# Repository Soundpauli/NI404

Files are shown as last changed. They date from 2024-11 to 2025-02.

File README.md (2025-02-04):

DIY OPEN SOURCE HARDWARE SAMPLER-SEQUENCER

---------
An Etch-A-SketchTM inspired device for beginners and makers.

THE OPEN SOURCE SAMPLE-SEQUENCER FOR EVERYONE.
-------------
The NI404 is an innovative, open-source DIY sample-sequencer from SP_ (aka soundpauli) - inspired by the classic Etch-A-Sketch, tailored for beginners and DIY enthusiasts. Designed around the Teensy Microcontroller and Audioboard from PJRC, this device offers an accessible entry point into the world of music creation.
The NI404 is more than just a musical instrument; it's a journey into the world of sound exploration, perfect for live performances, studio sessions, or simply having fun creating music. Whether you're a seasoned musician or a curious beginner, the NI404 is your gateway to an exciting world of musical possibilities.

EASY TO USE.
-------------
With its playful design, the NI404 lets users create complex sound patterns without any prior knowledge of musical instruments or equipment. It's perfect for beginners and makers alike.

DYNAMIC CONTROL DESPITE LESS BUTTONS.
-------------
At the heart of the NI404 is a vivid 16x16 RGB LED panel display, paired with three intuitive rotary-push encoders. Navigate a cursor across the grid, where each row signifies a voice and each column a potential note, allowing for up to 16 pitches per note. This feature enables the mixing of up to 8 voices simultaneously.

REAL-TIME INTERACTION.
-------------
Adjust samples, instruments, pitches, notes, volume, BPM, velocity, and effects in real-time without pausing. This seamless interaction makes the NI404 an ideal gadget for live performances.

CORE COMPONENTS.
-------------
Teensy 4.1 Microcontroller and Teensy Audio board (4.0)
8MB PSRAM Flash Memory
3 Rotary-push encoders
16x16 RGB-LED Panel driven by FastLED
3.5mm audio jack and removable SD Microcard slot

CREATIVE FLEXIBILITY.
-------------
Etch-A-Sketch style note drawing
On-the-fly note deletion and sample muting
Adjustable volume, BPM (40 - 200), pattern, and note velocity
Up to 30-second sample length with seamless looping
Use your own samples on the SD-Card - in a simple file structure
Load up to 8 voices / samples (Wav format) plus an additional onboard synth voice
16-bar patterns across 8 pages, totaling 128 bars per song
Save and load up to 100 patterns / songs on the SD card
Autosave and autoload functions
SAMPLES AT YOUR FINGERTIPS:
THE BUILT-IN SAMPLE BROWSER.
Access and manage samples while playing, with support for up to 999 samples on the SD card and the ability to predefine multiple voices as a SampleSet.

FULLY INDEPENDENT.
-------------
Operates without a computer, generating all sounds on the device itself. USB powered (5V) and Arduino code is published under the MIT License.

Important: The NI404 does not include speakers or Bluetooth connectivity; Headphones are recommended. Because of licensing: please use your own sample files (folder structure is included).

READY FOR MORE.
-------------
Potential updates include USB-MIDI In & Out, and possible new features you are builing ;)

HARDWARE LIST
-------------
Custom PCB - to connect the encoders to the Teensy (but you can also hard wire everything): see Downloads
1x Teensy 4.1
1x Teensy Audio Adaptor / TEENSY4_AUDIO
2x PSRAM Chip for Teensy 4.1
4x Rotary Encoder KY-040 360degree + Push

Jumper Wire Cables (10cm)
1x Micro SD Card (Class 10)
(Micro SD-Extension)
1x 16x16 RGB LED Matrix

USED LIBRARIES
-------------
WS2812Serial
Teensy Audio Library (Audio.h, v1.0.6)
Quadrature Encoder Library from Paul Stoffregen (Encoder.h, v1.4.4)
Mapf (v1.0.2, GPL-3.0 license)
FastLED (v3.9.10, MIT License)
TeensyPolyphony (v1.0.7, MIT License)

>Important notice:
Dont forget to replace the ResamplingReader.h inside the newdigate/teensy-variable-playback library with the one from this directory - It helps a lot fighting nullptr errors ;)

Compiler-Switches
-------------
USB-Type: (Serial)+MIDI16X

LICENSE
-------------
The code is released under the MIT License, which means it's freely available for personal and commercial use, modification, distribution, and private copying. This permissive license is part of our effort to support innovation and creativity.

However, while the NI404 code itself is under the MIT License, we urge every user to be mindful of the dependencies and libraries utilized within the code. Each of these components may be governed by its own set of licenses. It's crucial for users to verify and ensure that they are in compliance with the licenses of all dependencies and libraries used in their projects. This step is important to respect the legal and ethical frameworks of open-source software.

So, whether you're a seasoned developer or a curious beginner, feel free to dive into the code, explore, modify, and create. Just remember to stay informed and respectful of the licensing requirements of all software components you use.

BUY A NI404
-------------
If you don't like to build your own NI404 (which i would recommend, it's an awesome project even for beginners), you can purchase 
the advances project: TOERN. See toern.live or github for more information.

GRATITUDE
-------------
I would like to extend my heartfelt thanks to Paul Stoffregen and everyone involved at PJRC for their incredible work in creating the Teensy environment and hardware. The innovation and dedication evident in Teensy have significantly impacted the DIY and maker communities, enabling countless creative projects and technological advancements.

Additionally, my gratitude goes out to the broader community of developers and enthusiasts who have contributed libraries for this remarkable piece of hardware. Your collective efforts and shared knowledge have not only enhanced the capabilities of Teensy but have also fostered a spirit of collaboration and open-source development, especially to Nic Newdigate, who contributed the awesome teensy-polyphony library, which is the "soul" of this project. Thanks!

Thank you all for your hard work, ingenuity, and commitment to making the Teensy platform a powerful and accessible tool for creators around the world.

Jan from SP_
Hamburg, January 2024

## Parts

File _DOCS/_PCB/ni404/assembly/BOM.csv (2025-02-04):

Reference | Value | Footprint | Qty | lcsc#
C1 | 1u | Capacitor_SMD:C_0402_1005Metric | 1 | C52923
C2 | 1u | Capacitor_SMD:C_0402_1005Metric | 1 | C52923
C3 | 10u | Capacitor_SMD:C_0603_1608Metric | 1 | C19702
C4 | 10u | Capacitor_SMD:C_0603_1608Metric | 1 | C19702
C5 | 10u | Capacitor_SMD:C_0603_1608Metric | 1 | C19702
C7 | 1u | Capacitor_SMD:C_0402_1005Metric | 1 | C52923
C8 | 1u | Capacitor_SMD:C_0402_1005Metric | 1 | C52923
C9 | 1u | Capacitor_SMD:C_0402_1005Metric | 1 | C52923
C10 | 100n | Capacitor_SMD:C_0402_1005Metric | 1 | C77020
C11 | 100n | Capacitor_SMD:C_0402_1005Metric | 1 | C77020
C12 | 1u | Capacitor_SMD:C_0402_1005Metric | 1 | C52923
C13 | 150n | Capacitor_SMD:C_0402_1005Metric | 1 | C162182
C14 | 100n | Capacitor_SMD:C_0402_1005Metric | 1 | C77020
C15 | 100n | Capacitor_SMD:C_0402_1005Metric | 1 | C77020
C16 | 10u | Capacitor_SMD:C_0603_1608Metric | 1 | C19702
C17 | 10u | Capacitor_SMD:C_0603_1608Metric | 1 | C19702
C18 | 10u | Capacitor_SMD:C_0603_1608Metric | 1 | C19702
C19 | 10u | Capacitor_SMD:C_0603_1608Metric | 1 | C19702
C20 | 10u | Capacitor_SMD:C_0603_1608Metric | 1 | C19702
C21 | 100n | Capacitor_SMD:C_0402_1005Metric | 1 | C77020
C22 | 10u | Capacitor_SMD:C_0603_1608Metric | 1 | C19702
C23 | 1u | Capacitor_SMD:C_0402_1005Metric | 1 | C52923
C24 | 10u | Capacitor_SMD:C_0603_1608Metric | 1 | C19702
C25 | 1u | Capacitor_SMD:C_0402_1005Metric | 1 | C52923
D1 | BAT54J | Diode_SMD:D_SOD-323F | 1 | C130415
D2 | MBR0540 | Diode_SMD:D_SOD-123 | 1 | C116159
D3 | LED | LED_SMD:LED_0603_1608Metric | 1 | C2286
J1 | AudioJack3_Switch | Connector_Audio:Jack_6.35mm_Neutrik_NMJ6HCD2_Horizontal | 1 | C368502
J2 | CUI_SJ2-35863B1-SMT-TR | myLibKicad:CUI_SJ2-35863B1-SMT-TR | 1 | C4992707
J3 | CUI_SJ2-35863B1-SMT-TR | myLibKicad:CUI_SJ2-35863B1-SMT-TR | 1 | C4992707
J4 | USB_C_Receptacle_USB2.0 | Connector_USB:USB_C_Receptacle_HRO_TYPE-C-31-M-12 | 1 | C165948
J5 | AudioJack3_Switch | Connector_Audio:Jack_6.35mm_Neutrik_NMJ6HCD2_Horizontal | 1 | C368502
J6 | AudioJack3_Switch | Connector_Audio:Jack_6.35mm_Neutrik_NMJ6HCD2_Horizontal | 1 | C368502
J7 | AudioJack3_Switch | Connector_Audio:Jack_6.35mm_Neutrik_NMJ6HCD2_Horizontal | 1 | C368502
J8 | Micro_SD_Card | Connector_Card:microSD_HC_Hirose_DM3BT-DSF-PEJS | 1 | C597972
J9 | Conn_01x03 | Connector_JST:JST_PH_B3B-PH-K_1x03_P2.00mm_Vertical | 1 | C131339
J11 | Conn_01x05 | Connector_JST:JST_PH_B5B-PH-K_1x05_P2.00mm_Vertical | 1 | C157993
J12 | Conn_01x05 | Connector_JST:JST_PH_B5B-PH-K_1x05_P2.00mm_Vertical | 1 | C157993
J13 | Conn_01x05 | Connector_JST:JST_PH_B5B-PH-K_1x05_P2.00mm_Vertical | 1 | C157993
J14 | Conn_01x05 | Connector_JST:JST_PH_B5B-PH-K_1x05_P2.00mm_Vertical | 1 | C157993
J15 | Conn_01x05 | Connector_JST:JST_PH_B5B-PH-K_1x05_P2.00mm_Vertical | 1 | C157993
J16 | BATTERY | Connector_JST:JST_PH_B2B-PH-K_1x02_P2.00mm_Vertical | 1 | C131337
MK1 | Microphone_Condenser | Sensor_Audio:POM-2244P-C3310-2-R | 1 | C3273559
Q1 | DMG3415 | Package_TO_SOT_SMD:SOT-23 | 1 | C7202986
R1 | 22R | Resistor_SMD:R_0402_1005Metric | 1 | C25092
R2 | 22R | Resistor_SMD:R_0402_1005Metric | 1 | C25092
R3 | 22R | Resistor_SMD:R_0402_1005Metric | 1 | C25092
R4 | 22R | Resistor_SMD:R_0402_1005Metric | 1 | C25092
R5 | 22R | Resistor_SMD:R_0402_1005Metric | 1 | C25092
R6 | 220R | Resistor_SMD:R_0603_1608Metric | 1 | C22962
R7 | 220R | Resistor_SMD:R_0603_1608Metric | 1 | C22962
R8 | 220R | Resistor_SMD:R_0603_1608Metric | 1 | C22962
R9 | 5.1k | Resistor_SMD:R_0402_1005Metric | 1 | C25905
R10 | 5.1k | Resistor_SMD:R_0402_1005Metric | 1 | C25905
R11 | 2k2 | Resistor_SMD:R_0603_1608Metric | 1 | C4190
R12 | 10k | Resistor_SMD:R_0402_1005Metric | 1 | C98220
R13 | 10k | Resistor_SMD:R_0402_1005Metric | 1 | C98220
R14 | 2k | Resistor_SMD:R_0603_1608Metric | 1 | C22975
R16 | 10k | Resistor_SMD:R_0402_1005Metric | 1 | C98220
R17 | 10k | Resistor_SMD:R_0402_1005Metric | 1 | C98220
R18 | 2k | Resistor_SMD:R_0603_1608Metric | 1 | C22975
SW1 | EG2219 | myLibKicad:EG2219 | 1 | C3664594
U1 | SPX3819M5-L-3-3 | Package_TO_SOT_SMD:SOT-23-5 | 1 | C9055
U2 | SPX3819M5-L-1-8 | Package_TO_SOT_SMD:SOT-23-5 | 1 | C24639
U3 | SGTL5000XNBA3 | Package_DFN_QFN:QFN-32-1EP_5x5mm_P0.5mm_EP3.6x3.6mm | 1 | C5196742
U4 | TLP2361V4_E | myLibKicad:5pin SO6_TOS | 1 | C107626
U5 | 74LVC2G14 | Package_TO_SOT_SMD:SOT-23-6 | 1 | C12401
U7 | SPX3819M5-L-3-3 | Package_TO_SOT_SMD:SOT-23-5 | 1 | C9055
U8 | MCP73831-3-OT | Package_TO_SOT_SMD:SOT-23-5 | 1 | C14879
U9 | 01x05 Connector_PinSocket_2.54mm | Connector_PinSocket_2.54mm:DuppaI2CEncoderV2.1 | 1 | C50950
U10 | 01x05 Connector_PinSocket_2.54mm | Connector_PinSocket_2.54mm:DuppaI2CEncoderV2.1 | 1 | C50950
U11 | 01x05 Connector_PinSocket_2.54mm | Connector_PinSocket_2.54mm:DuppaI2CEncoderV2.1 | 1 | C50950
U12 | 01x05 Connector_PinSocket_2.54mm | Connector_PinSocket_2.54mm:DuppaI2CEncoderV2.1 | 1 | C50950
U13 | 01x05 Connector_PinSocket_2.54mm | Connector_PinSocket_2.54mm:DuppaI2CEncoderV2.1 | 1 | C50950
U14 | 01x05 Connector_PinSocket_2.54mm | Connector_PinSocket_2.54mm:DuppaI2CEncoderV2.1 | 1 | C50950
U15 | 01x05 Connector_PinSocket_2.54mm | Connector_PinSocket_2.54mm:DuppaI2CEncoderV2.1 | 1 | C50950
U16 | 01x05 Connector_PinSocket_2.54mm | Connector_PinSocket_2.54mm:DuppaI2CEncoderV2.1 | 1 | C50950

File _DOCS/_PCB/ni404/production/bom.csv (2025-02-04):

Designator | Footprint | Quantity | Value | LCSC Part #
J11, J12, J13, J14, J15 | JST_PH_B5B-PH-K_1x05_P2.00mm_Vertical | 5 | Conn_01x05
J9 | JST_PH_B3B-PH-K_1x03_P2.00mm_Vertical | 1 | Conn_01x03

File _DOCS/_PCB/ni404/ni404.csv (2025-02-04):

Id | Designator | Footprint | Quantity | Designation | Supplier and ref
1 | J15,J11,J12,J13,J14 | JST_PH_B5B-PH-K_1x05_P2.00mm_Vertical | 5 | Conn_01x05
2 | J9 | JST_PH_B3B-PH-K_1x03_P2.00mm_Vertical | 1 | Conn_01x03

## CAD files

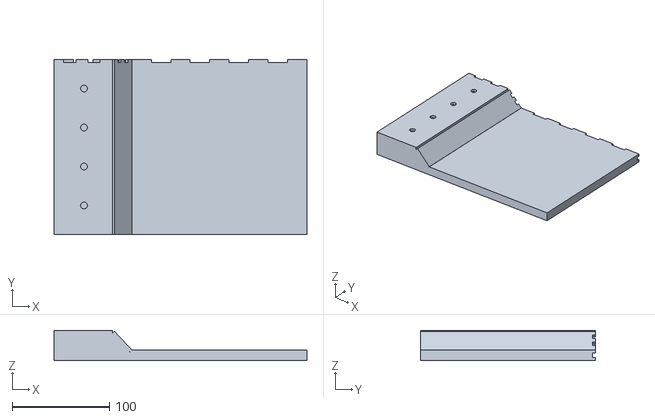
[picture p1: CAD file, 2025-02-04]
_DOCS/_ENCLOSURE/ni404 completed.stl
260.0 x 180.0 x 31.0

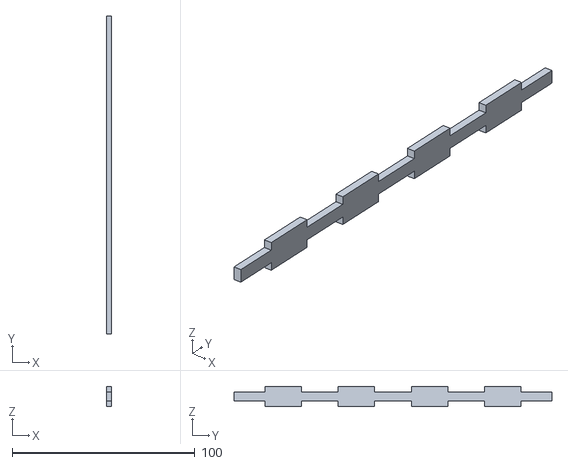
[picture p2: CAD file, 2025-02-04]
_DOCS/_ENCLOSURE/ni404_front.stl
3.00 x 174.0 x 11.0

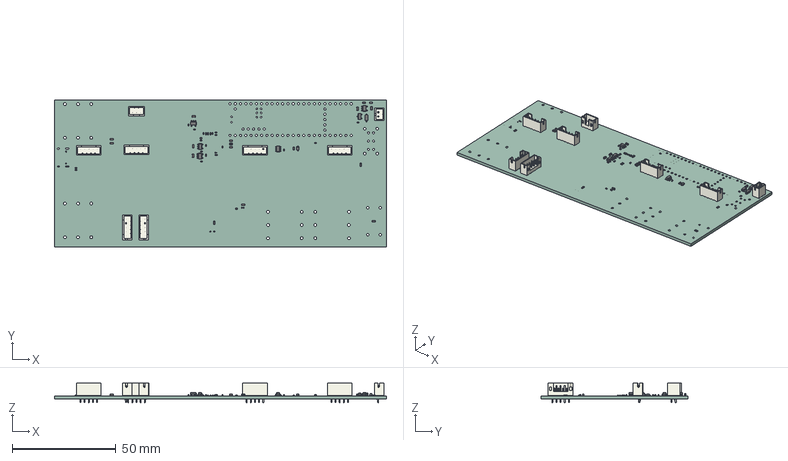
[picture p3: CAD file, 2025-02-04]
_DOCS/_PCB/ni404/ni404.step
160.0 x 71.0 x 9.40 mm
D_SOD_123
C_0402_1005Metric x 14
R_0603_1608Metric x 6
R_0402_1005Metric x 11
JST_B5B_PH_K x 6
C_0603_1608Metric x 10
SOT_23_6
SOT_23_5 x 4
JST_B3B_PH_K
LED_0603_1608Metric
SOT_23
JST_B2B_PH_K
D_SOD_323F
teensyAudioMidi_PCB

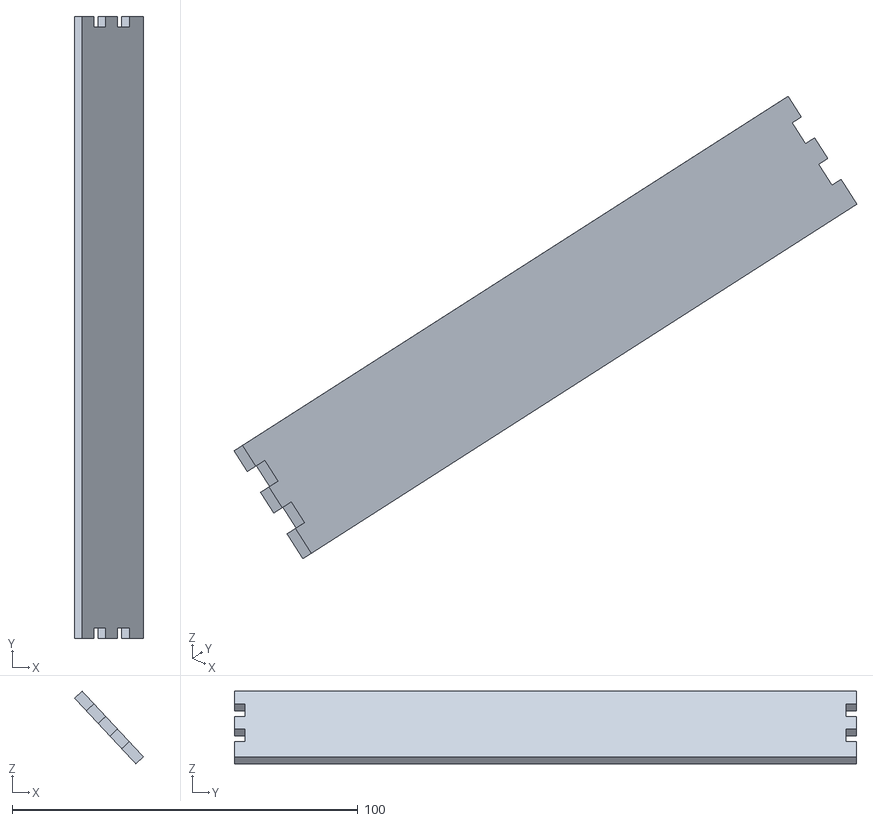
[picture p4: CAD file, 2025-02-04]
_DOCS/_ENCLOSURE/ni404_frontplate.stl
19.9 x 180.0 x 21.1

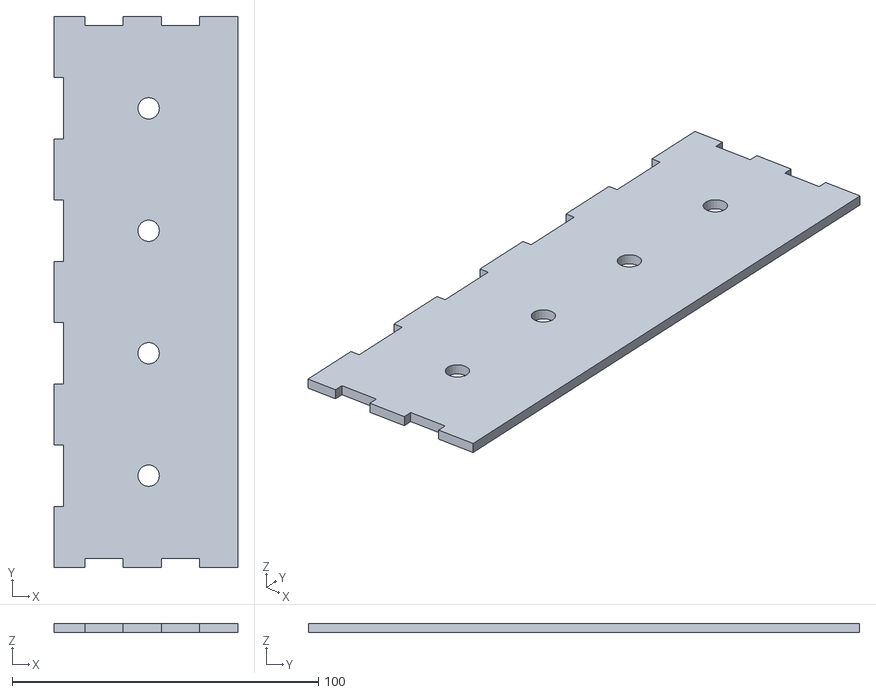
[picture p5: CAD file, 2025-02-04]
_DOCS/_ENCLOSURE/ni404_top.stl
60.0 x 180.0 x 3.00

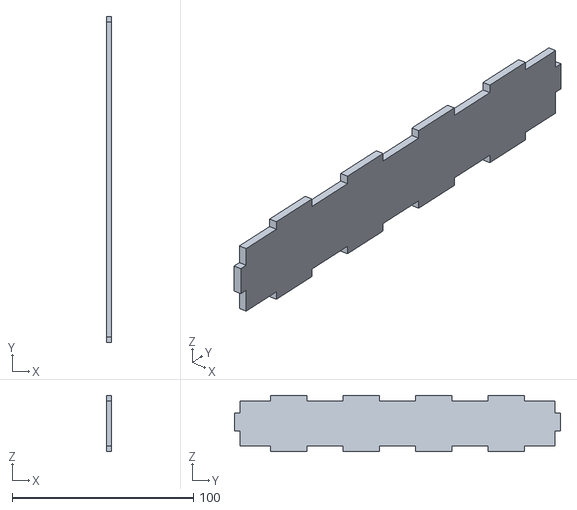
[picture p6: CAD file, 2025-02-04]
_DOCS/_ENCLOSURE/ni404_back.stl
3.00 x 180.0 x 31.0

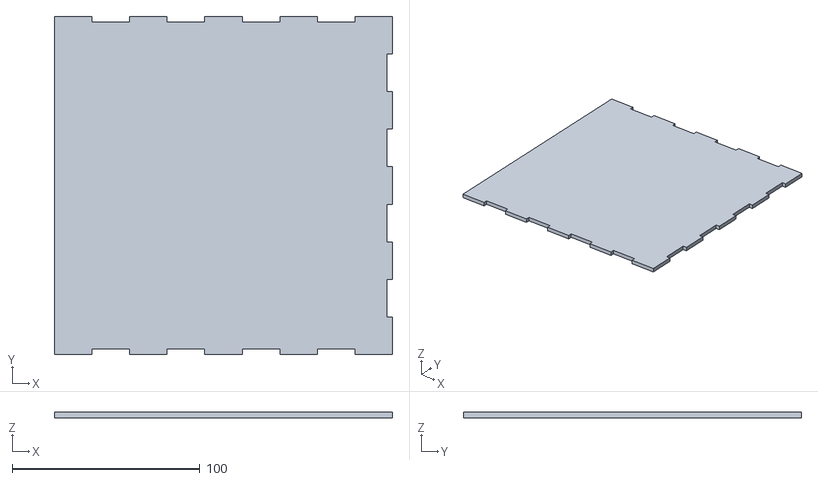
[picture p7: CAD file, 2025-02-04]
_DOCS/_ENCLOSURE/ni404_glassplate.stl
180.0 x 180.0 x 3.00

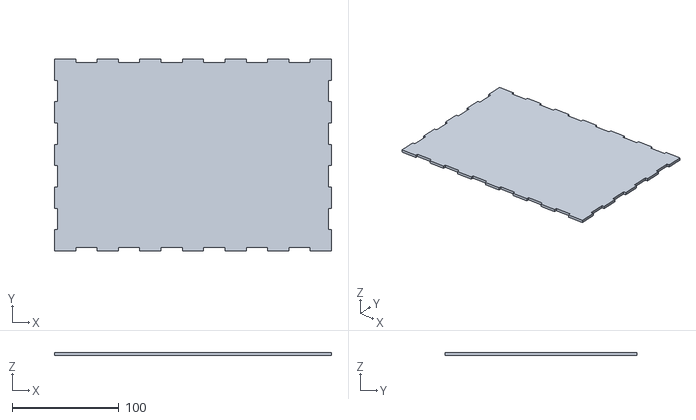
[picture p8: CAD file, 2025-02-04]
_DOCS/_ENCLOSURE/ni404_base.stl
260.0 x 180.0 x 3.00

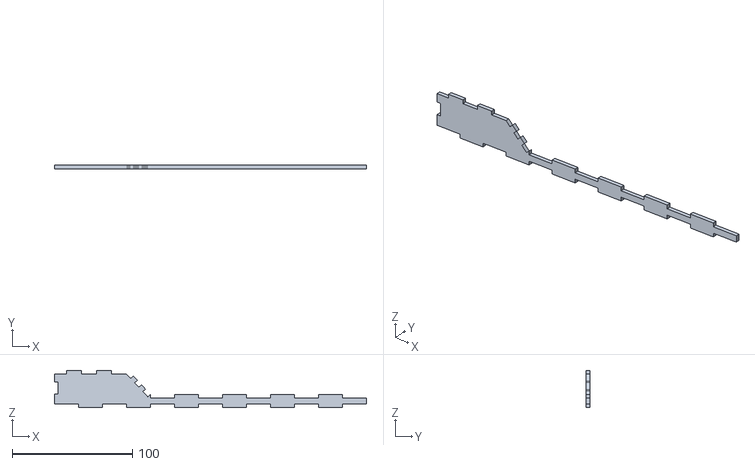
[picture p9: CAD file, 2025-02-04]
_DOCS/_ENCLOSURE/ni404_sides.stl
260.0 x 3.00 x 31.0

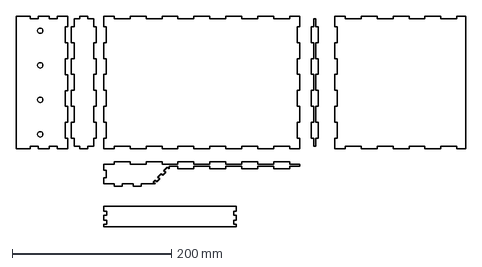
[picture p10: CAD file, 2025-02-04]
_DOCS/_ENCLOSURE/ni_404.dxf
564.2 x 264.5 mm

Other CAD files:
_DOCS/_ENCLOSURE/ni_404.f3d

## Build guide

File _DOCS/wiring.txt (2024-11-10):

Wiring for 3-4 Encoder-Version (1.0-1.x)
------------------------------------------------

> LED-Matrix:
DIN - Teensy: 17
+5V - Teensy: +5V
GND - Teensy: GND

> Encoder Left:
CLK - Teensy: 5
DT  - Teensy: 22
Switch - Teensy: 15
+3v - 3V
GND - GND

> Encoder Middle left:
CLK - Teensy: 32
DT  - Teensy: 33
Switch  - Teensy: 41
+3v - 3V
GND - GND

> Encoder Middle right:
CLK - Teensy: 9
DT  - Teensy: 14
Switch  - Teensy: 16
+3v - 3V
GND - GND

> Encoder Right:
CLK - Teensy: 4
DT  - Teensy: 2
Switch  - Teensy: 3
+3v - 3V
GND - GND

> DAC_PCB (backpack-PCB until v.1.x, included in v.2)
BCK - Teensy: 21
DIN - Teensy: 7
DOUT - Teensy: 8
WS  - Teensy: 20
+3  - 3V
GND - GND

Overall used pins:
------------------------------------------------

0   ->  MIDI IN 
1   ->  MIDI OUT
2   ->  NI=>Right Encoder CLOCK
3   ->  NI=>Right Encoder BUTTON
4   ->  NI=>Right Encoder BUS
5   ->  NI=>Left Encoder CLOCK
6   ->  MEMORYCHIP  
7   ->  AudioDAC DIN
8   ->  AudioDAC DOUT
9   ->  NI=>Middle Encoder CLOCK
10  ->  ChipSelect CS for SD 
11  ->  Data Storage (SPI) from Teensy to SD/MEM
12  ->  Data Storage (SPI) from SD/MEM to Teensy
13  ->  Data Storage (SPI) Clock
14  ->  NI=>Middle Encoder BUS
15  ->  NI=> Left Encoder BUTTON (+volume?)
16  ->  NI=> Middle Encoder BUTTON
17  ->  NI=> LED-MAXTRIX DIN
18  ->  Control Data (I2C)
19  ->  Control Clock (I2C)
20  ->  Audio Left/Right Clock, 44.1 kHz
21  ->  Audio Bit Clock, 1.41 or 2.82 MHz
22  ->  NI=>Left Encoder BUS
23  ->  Audio Master Clock, 11.29 MHz
32  ->  NI=>Middle Encoder BUS
33  ->  NI=>Middle Encoder CLOCK
41  ->  NI=>Middle Encoder BUTTON

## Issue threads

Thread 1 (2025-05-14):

Compiling issue

sinitsinmike, 2025-05-14:
After installing libraries of specified version I'm having issue compiling.
Followed the readme.
Is it possible to share precompiled hex file for the teensy4.1. it would be very easy to flash the hex file even for inexperienced users :)

Thank you!

sinitsinmike, 2025-05-14:
Tried compiling using arduino ide and VS Code.
I have failed to compile in both cases ;)
I've contacted you over the email. Applied your suggestions, but still no luck.

In any case just wanted to thank you for the great project and for trying to help.
I'm no pro in programming, but quite good at soldering :)

Thanks again!
Michael

Soundpauli, 2025-05-14:
Could you post the full compiler output including all used libraries+versions?
It seems as if you might be using the wrong versions of the newdigate libraries:

IDE 2.3.2
Teensyduino 1.59.0
Encoder 1.4.4
adv_switch 1.2.7  (or 1.2.8)
FastLED 3.9.16

>> Audiosample aka Teensy-Polyphony: https://github.com/newdigate/teensy-polyphony 1.0.7
>> Teensy-Variable-Playback:  https://github.com/newdigate/teensy-variable-playback 1.0.16

Please set to these versions and try again

sinitsinmike, 2025-05-14:
Will doublecheck the versions.

At this point I get:

[NI404 build log.txt](https://github.com/user-attachments/files/20213698/NI404.build.log.txt)
This is actually an *.rtf file. Not allowed to attach those. So just changed the extension.

sinitsinmike, 2025-05-14:
Changed some lib versions.
Attaching a txt log.

[NI404 build log2.txt](https://github.com/user-attachments/files/20213824/NI404.build.log2.txt)

sinitsinmike, 2025-05-14:
Tried the versions specified in README.md
USED LIBRARIES
-------------
WS2812Serial
Teensy Audio Library (Audio.h, v1.0.6)
Quadrature Encoder Library from Paul Stoffregen (Encoder.h, v1.4.4)
Mapf (v1.0.2, GPL-3.0 license)
FastLED (v3.9.10, MIT License)
TeensyPolyphony (v1.0.7, MIT License)

Should these be:
FastLED 3.9.16? instead of v3.9.10?

sinitsinmike, 2025-05-14:
Multiple libraries were found for "Encoder.h"
  Used: /Users/michaelsinitsin/Documents/Arduino/libraries/Encoder
  Not used: /Users/michaelsinitsin/Library/Arduino15/packages/teensy/hardware/avr/1.59.0/libraries/Encoder
Using library Mapf at version 1.0.2 in folder: /Users/michaelsinitsin/Documents/Arduino/libraries/Mapf
Using library WS2812Serial in folder: /Users/michaelsinitsin/Library/Arduino15/packages/teensy/hardware/avr/1.59.0/libraries/WS2812Serial (legacy)
Using library FastLED at version 3.9.16 in folder: /Users/michaelsinitsin/Documents/Arduino/libraries/FastLED
Using library SPI at version 1.0 in folder: /Users/michaelsinitsin/Library/Arduino15/packages/teensy/hardware/avr/1.59.0/libraries/SPI
Using library Audio at version 1.3 in folder: /Users/michaelsinitsin/Library/Arduino15/packages/teensy/hardware/avr/1.59.0/libraries/Audio
Using library SD at version 2.0.0 in folder: /Users/michaelsinitsin/Library/Arduino15/packages/teensy/hardware/avr/1.59.0/libraries/SD
Using library SdFat at version 2.1.2 in folder: /Users/michaelsinitsin/Library/Arduino15/packages/teensy/hardware/avr/1.59.0/libraries/SdFat
Using library SerialFlash at version 0.5 in folder: /Users/michaelsinitsin/Library/Arduino15/packages/teensy/hardware/avr/1.59.0/libraries/SerialFlash
Using library Encoder at version 1.4.4 in folder: /Users/michaelsinitsin/Documents/Arduino/libraries/Encoder
Using library Switch at version 1.2.7 in folder: /Users/michaelsinitsin/Documents/Arduino/libraries/Switch
Using library EEPROM at version 2.0 in folder: /Users/michaelsinitsin/Library/Arduino15/packages/teensy/hardware/avr/1.59.0/libraries/EEPROM
Using library TeensyAudioSampler at version 1.0.7 in folder: /Users/michaelsinitsin/Documents/Arduino/libraries/TeensyAudioSampler
Using library TeensyVariablePlayback at version 1.0.16 in folder: /Users/michaelsinitsin/Documents/Arduino/libraries/TeensyVariablePlayback
Using library LittleFS at version 1.0.0 in folder: /Users/michaelsinitsin/Library/Arduino15/packages/teensy/hardware/avr/1.59.0/libraries/LittleFS
Using library Wire at version 1.0 in folder: /Users/michaelsinitsin/Library/Arduino15/packages/teensy/hardware/avr/1.59.0/libraries/Wire
exit status 1

Soundpauli, 2025-05-15:
Solution 1:
make sure to #include "Arduino.h" in the main ino.

>From Arduino.h:

typedef unsigned int word;
typedef uint8_t boolean;
typedef uint8_t byte;

Solution 2:
At the top of any .h or .cpp file in TeensyAudioSampler that uses byte, add:

"using ::byte;"

This will make sure it resolves to the Arduino-style uint8_t version.
Alternative Fix (More Explicit): Change all uses of byte to uint8_t in the code.

sinitsinmike, 2025-05-15:
Thank you!
Where do I need to paste the following?:
"From Arduino.h:

typedef unsigned int word;
typedef uint8_t boolean;
typedef uint8_t byte; "

sinitsinmike, 2025-05-15:
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
Using this one.

sinitsinmike, 2025-05-16:
Are you using VS Code for compiling? Or something else?
I've found your new upcoming project. You've mentioned it is not ready on the web page.
Tried to build that one as well and failed :)

Soundpauli, 2025-05-23:
did you manage to compile?
if not, i added a precompiled hex file in the git, finally :)

[](https://github.com/Soundpauli/NI404/blob/main/build/teensy.avr.teensy41/soundpauli_ni404.ino.hex)

Soundpauli, 2025-05-23:
the teensy audio library uses the  stgl5000 at the moment. but you can change this in the code, i guess:

https://forum.pjrc.com/index.php?threads/pcm5012-i2s-dac-with-teensy-4-1.68625/

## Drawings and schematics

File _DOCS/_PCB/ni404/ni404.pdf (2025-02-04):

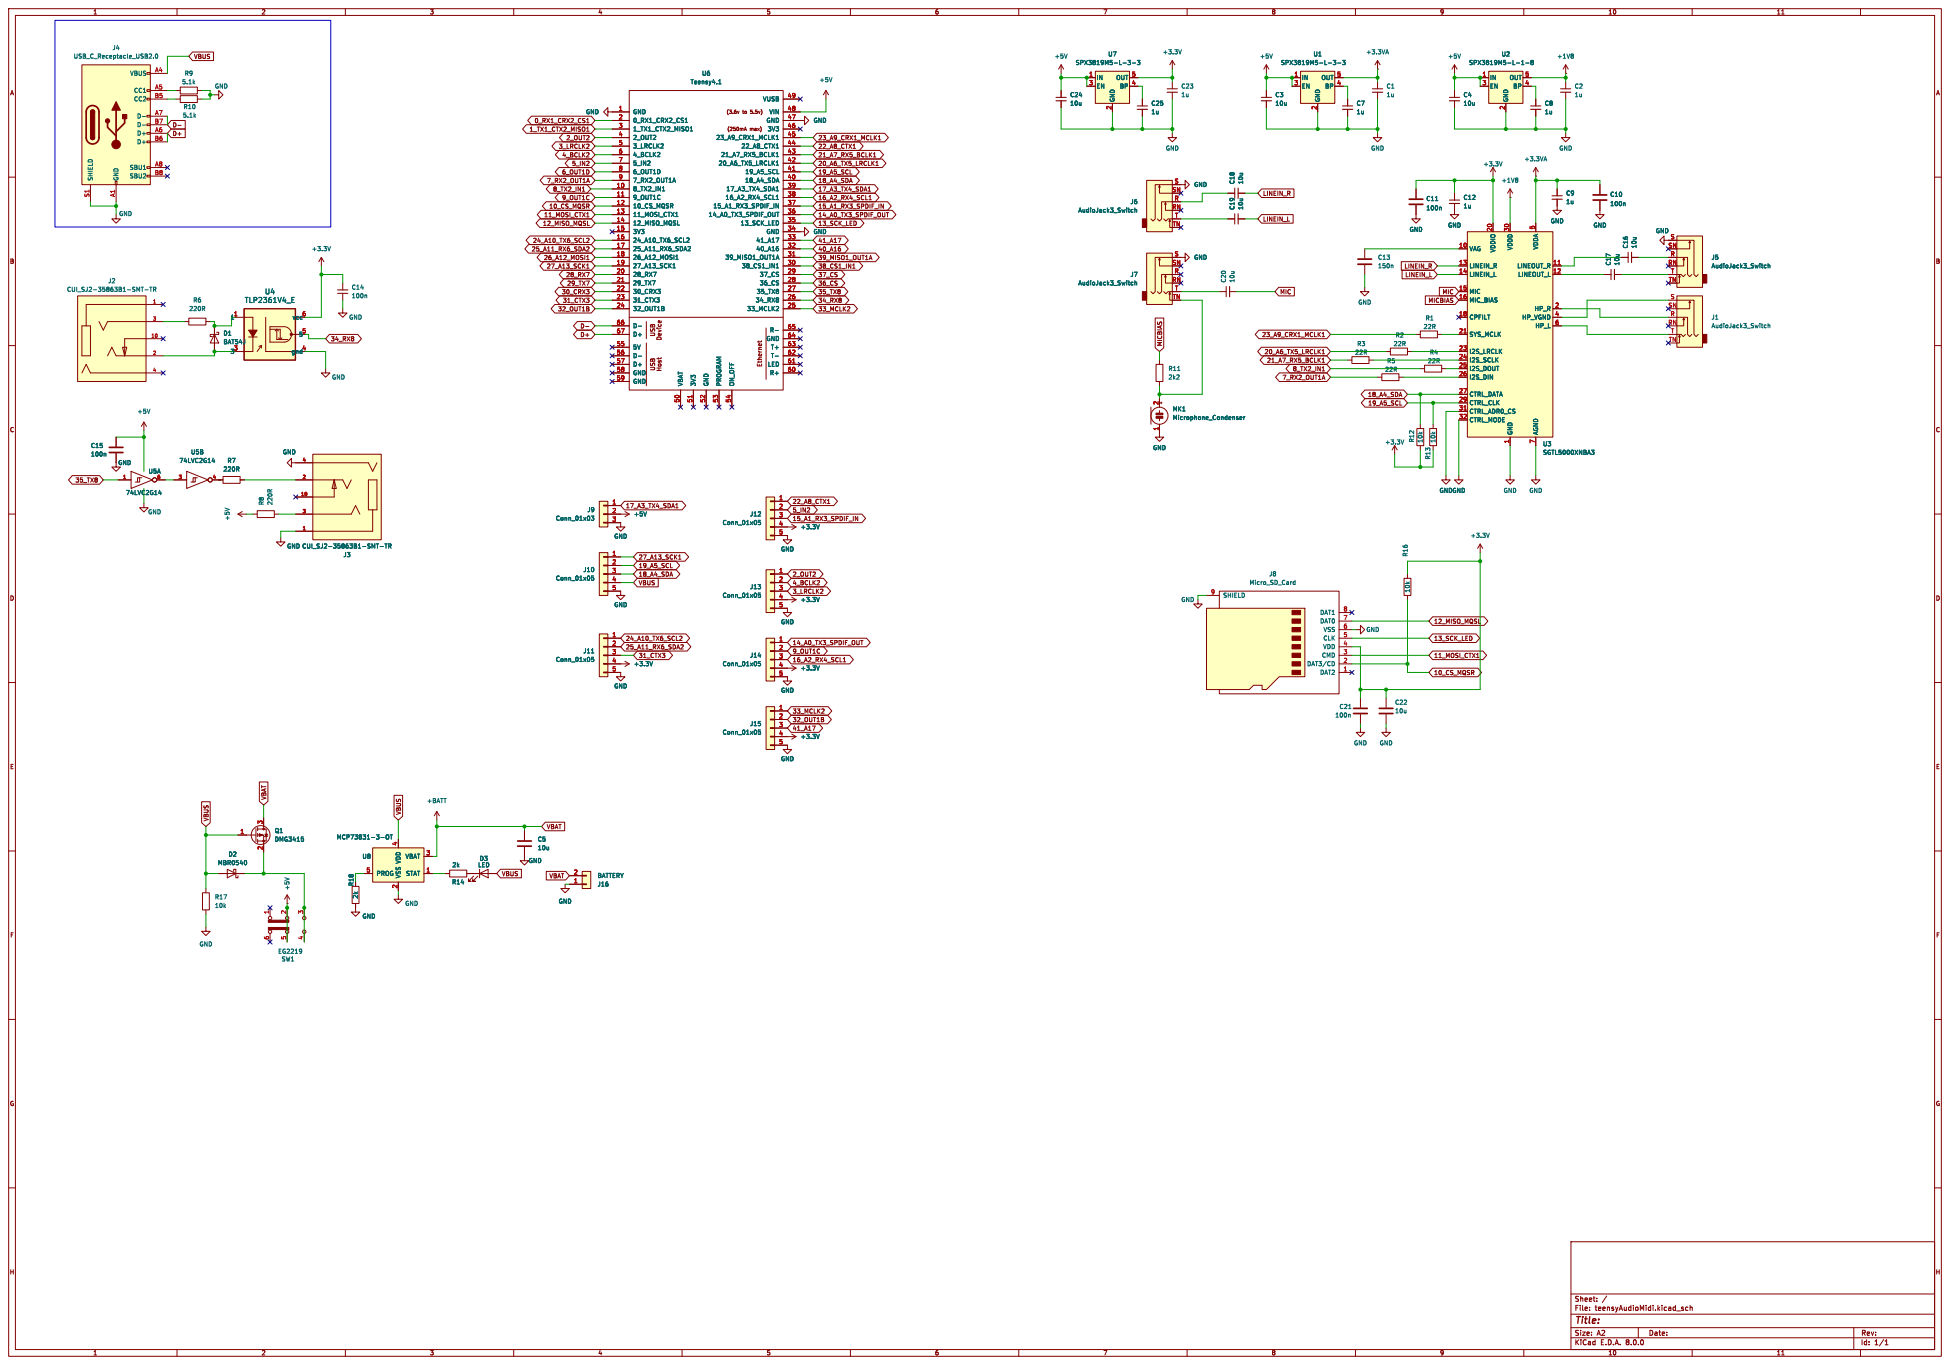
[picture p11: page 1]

4 PROG 5U8 MCP73831-3-OT GND GND

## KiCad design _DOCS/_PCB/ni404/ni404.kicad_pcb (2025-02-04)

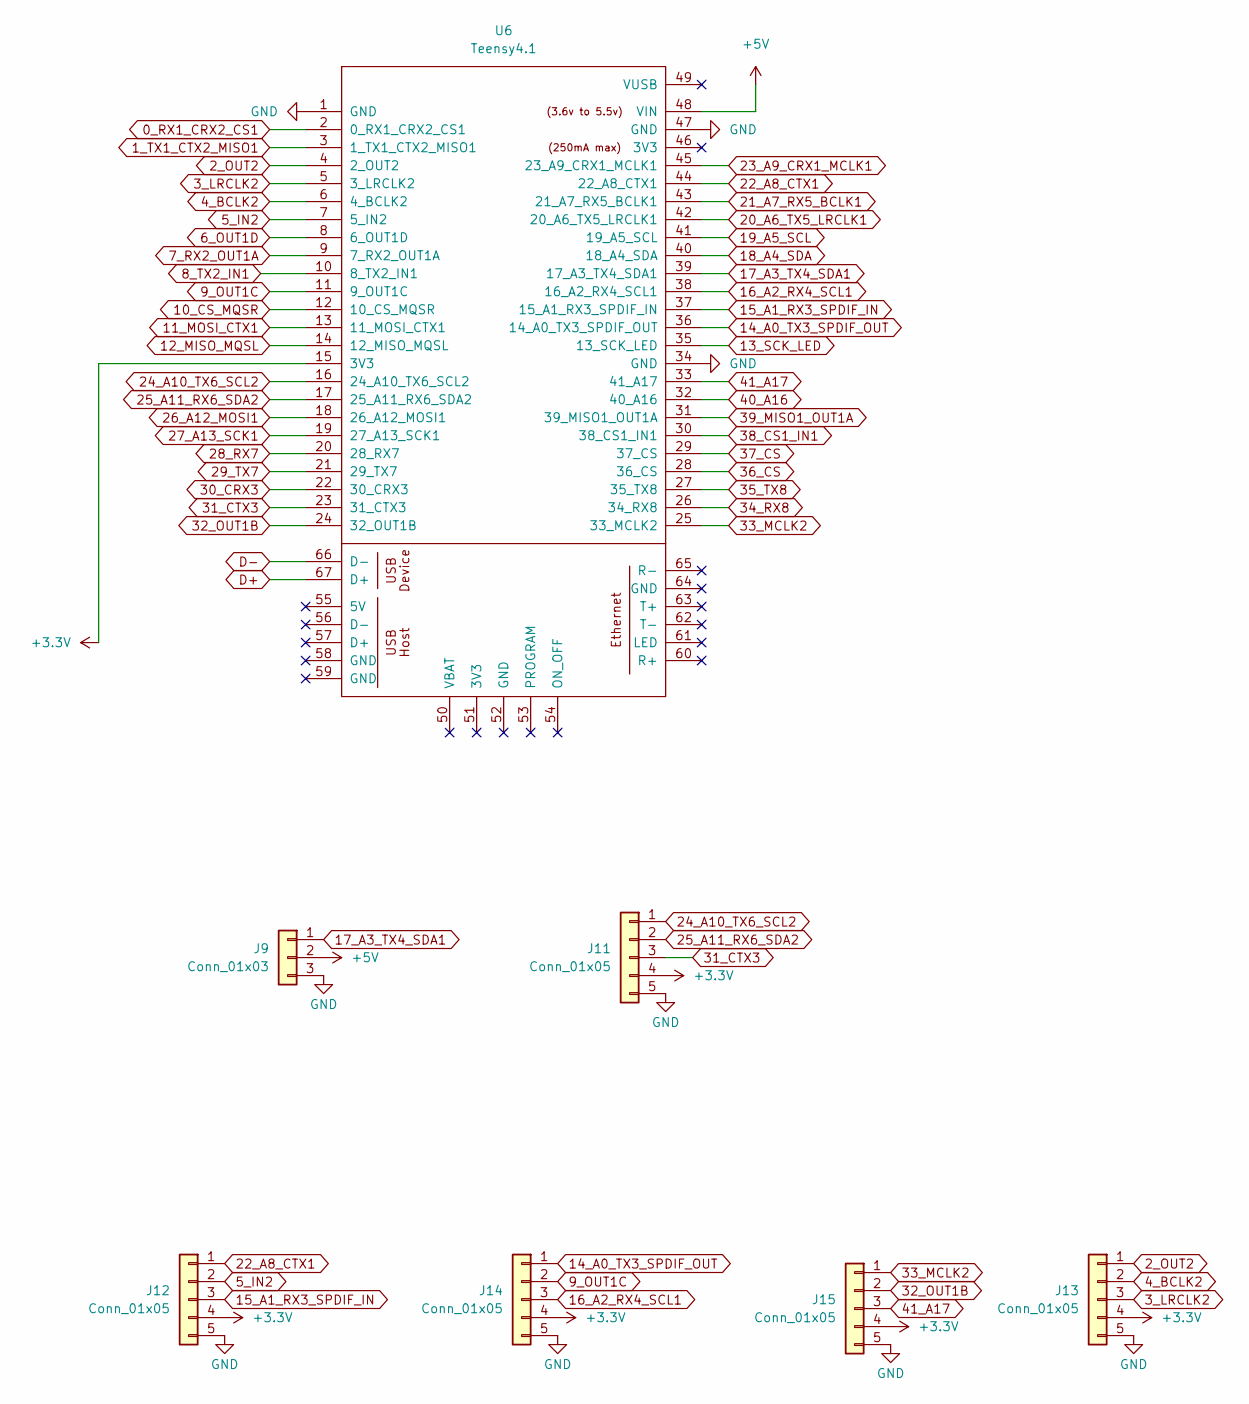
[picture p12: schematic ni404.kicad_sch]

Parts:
J9: Conn_01x03; JST_PH_B3B-PH-K_1x03_P2.00mm_Vertical; lcsc# C131339
J11, J12, J13, J14, J15: Conn_01x05; JST_PH_B5B-PH-K_1x05_P2.00mm_Vertical; lcsc# C157993
U6: Teensy4.1; Teensy41; lcsc# ----

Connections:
0_RX1_CRX2_CS1: U6.2 (0_RX1_CRX2_CS1)
1_TX1_CTX2_MISO1: U6.3 (1_TX1_CTX2_MISO1)
2_OUT2: J13.1, U6.4 (2_OUT2)
3_LRCLK2: J13.3, U6.5 (3_LRCLK2)
4_BCLK2: J13.2, U6.6 (4_BCLK2)
5_IN2: J12.2, U6.7 (5_IN2)
6_OUT1D: U6.8 (6_OUT1D)
7_RX2_OUT1A: U6.9 (7_RX2_OUT1A)
8_TX2_IN1: U6.10 (8_TX2_IN1)
9_OUT1C: J14.2, U6.11 (9_OUT1C)
10_CS_MQSR: U6.12 (10_CS_MQSR)
11_MOSI_CTX1: U6.13 (11_MOSI_CTX1)
12_MISO_MQSL: U6.14 (12_MISO_MQSL)
13_SCK_LED: U6.35 (13_SCK_LED)
14_A0_TX3_SPDIF_OUT: J14.1, U6.36 (14_A0_TX3_SPDIF_OUT)
15_A1_RX3_SPDIF_IN: J12.3, U6.37 (15_A1_RX3_SPDIF_IN)
16_A2_RX4_SCL1: J14.3, U6.38 (16_A2_RX4_SCL1)
17_A3_TX4_SDA1: J9.1, U6.39 (17_A3_TX4_SDA1)
18_A4_SDA: U6.40 (18_A4_SDA)
19_A5_SCL: U6.41 (19_A5_SCL)
20_A6_TX5_LRCLK1: U6.42 (20_A6_TX5_LRCLK1)
21_A7_RX5_BCLK1: U6.43 (21_A7_RX5_BCLK1)
22_A8_CTX1: J12.1, U6.44 (22_A8_CTX1)
23_A9_CRX1_MCLK1: U6.45 (23_A9_CRX1_MCLK1)
24_A10_TX6_SCL2: J11.1, U6.16 (24_A10_TX6_SCL2)
25_A11_RX6_SDA2: J11.2, U6.17 (25_A11_RX6_SDA2)
26_A12_MOSI1: U6.18 (26_A12_MOSI1)
27_A13_SCK1: U6.19 (27_A13_SCK1)
28_RX7: U6.20 (28_RX7)
29_TX7: U6.21 (29_TX7)
30_CRX3: U6.22 (30_CRX3)
31_CTX3: J11.3, U6.23 (31_CTX3)
32_OUT1B: J15.2, U6.24 (32_OUT1B)
33_MCLK2: J15.1, U6.25 (33_MCLK2)
34_RX8: U6.26 (34_RX8)
35_TX8: U6.27 (35_TX8)
36_CS: U6.28 (36_CS)
37_CS: U6.29 (37_CS)
38_CS1_IN1: U6.30 (38_CS1_IN1)
39_MISO1_OUT1A: U6.31 (39_MISO1_OUT1A)
40_A16: U6.32 (40_A16)
41_A17: J15.3, U6.33 (41_A17)
+3.3V: J11.4, J12.4, J13.4, J14.4, J15.4, U6.15 (3V3)
+5V: J9.2, U6.48 (VIN)
D+: U6.67 (D+)
D-: U6.66 (D-)
GND: J9.3, J11.5, J12.5, J13.5, J14.5, J15.5, U6.1 (GND), U6.34 (GND), U6.47 (GND)

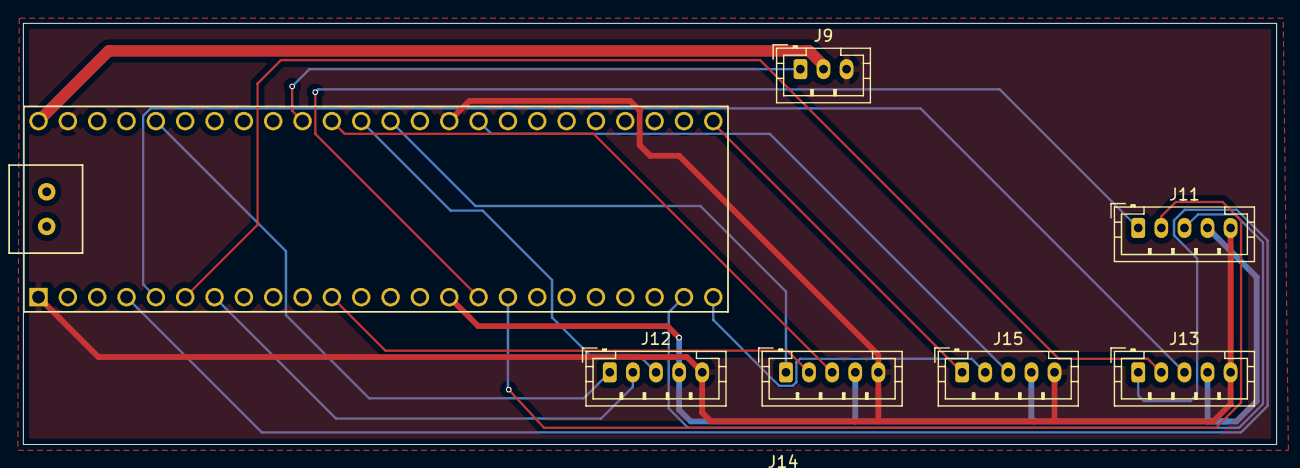
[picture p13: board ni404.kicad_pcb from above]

Board: 2 copper layers, 108.5 x 36.5 mm, 7 parts (0 on the bottom side), 19 nets.

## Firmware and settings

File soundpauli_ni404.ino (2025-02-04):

/* THIS IS SP_ NI404 */
/* Sadly, this project isnt continued anymore in this format.*/
/* This code compiles and works as a great start for adventures in sound, but is far from completion */
/* BUT: This is Open-Source-MIT-licensed Software - make it better and contribute! */
/**/
/* Feel free to check out its successor project toern (http://github.com/Soundpauli/toern) */



#define FASTLED_ALLOW_INTERRUPTS 1
#define AUDIO_SAMPLE_RATE_EXACT 44100.0
#define TargetFPS 27

#include "Arduino.h"
#include <Mapf.h>
#include <WS2812Serial.h>  // leds
#define USE_WS2812SERIAL   // leds
#include <FastLED.h>       // leds
#include <Audio.h>
#include <Encoder.h>
#include "avdweb_Switch.h"
#include <EEPROM.h>
#include <cstring>  // For memcmp
#include "colors.h"
#include "files.h"
#include <TeensyPolyphony.h>
#include "audioinit.h"

#define SD_SLOT BUILTIN_SDCARD
#define NUM_LEDS 256
#define DATA_PIN 17
int lastFile[9] = { 0 };
bool tmpMute = false;
const unsigned int defaultVelocity = 63;
const unsigned int maxX = 16;
const unsigned int maxY = 16;
const unsigned int maxPages = 8;
const unsigned int maxFiles = 9;  // 12 samples, 2 Synths
const unsigned int maxFilters = 15;
const unsigned int maxlen = (maxX * maxPages) + 1;
const long ram = 15989988 - 5000 - 22168 - 5000;  // 16MB total, - 5kb for images+Icons, - 22kb for notes[]
const unsigned int SONG_LEN = maxX * maxPages;
const unsigned int maxBPM = 240;
const unsigned int maxVolume = 10;
const unsigned int maxFolders = 9;
const unsigned int numPulsesForAverage = 24;  // Number of pulses to average over
const unsigned int pulsesPerBar = 24 * 4;     // 24 pulses per quarter note, 4 quarter notes per bar
const unsigned int barsToWait = 2;
const unsigned int maxfilterResolution = 32;
const unsigned int totalPulsesToWait = pulsesPerBar * barsToWait;

// runtime
//  variables for program logic
unsigned int playNoteInterval = 150000;
unsigned int RefreshTime = 1000 / TargetFPS;
float marqueePos = maxX;
bool shifted = false;
bool movingForward = true;  // Variable to track the direction of movement
unsigned volatile int lastUpdate;
volatile unsigned int lastClockTime = 0;
volatile unsigned int totalInterval = 0;
volatile unsigned int clockCount = 0;
bool hasNotes[maxPages + 1];
unsigned int startTime = 0;    // Variable to store the start time
bool noteOnTriggered = false;  // Flag to indicate if noteOn has been triggered
volatile bool waitForFourBars = false;
volatile unsigned int pulseCount = 0;
bool sampleIsLoaded = false;
bool unpaintMode, paintMode = false;
String oldButtonString = "";
String buttonString = "";
String oldPos = "";
unsigned int pagebeat, beat = 1;
unsigned int samplePackID, fileID = 1;
EXTMEM unsigned int lastPreviewedSample[maxFolders] = {};
IntervalTimer playTimer;
unsigned int lastPage = 1;
unsigned int lastButtonPressTime = 0;
bool resetTimerActive = false;
EXTMEM unsigned int previousEncoderValues[4];
float pulse = 1;
int dir = 1;
EXTMEM unsigned int tmp[maxlen][maxY + 1][2] = {};
EXTMEM unsigned int original[maxlen][maxY + 1][2] = {};
EXTMEM unsigned int note[maxlen][maxY + 1][2] = {};
unsigned int sample_len[maxFiles];
bool sampleLengthSet = false;
bool isPlaying = false;  // global
int PrevSampleRate = 1;
EXTMEM int SampleRate[16] = { 1, 1, 1, 1, 1, 1, 1, 1, 1, 1, 1, 1, 1, 1, 1, 1 };
EXTMEM int buttons[5], oldButtons[5] = { 0, 0, 0, 0, 0 };
EXTMEM unsigned char sampled[maxFiles][ram / (maxFiles + 1)];

const float pianoFrequencies[16] = {
  130.81,  // C3
  146.83,  // D3
  164.81,  // E3
  174.61,  // F3
  196.00,  // G3
  220.00,  // A3
  246.94,  // B3
  261.62,  // C4 (Mitte)
  293.66,  // D4
  329.62,  // E4
  349.22,  // F4
  391.99,  // G4
  440.00,  // A4
  493.88,  // B4
  523.25,  // C5
  587.33   // D5
};


CRGB leds[NUM_LEDS];

struct Mode {
  String name;
  unsigned int minValues[4];
  unsigned int maxValues[4];
  unsigned int pos[4];
};

// Declare the modes aka max states for encoders and their min/max values
// min (l-m-m2-r),max(l-m-m2-r), pos(l-m-m2-r)
Mode draw = { "DRAW", { 1, 1, 1, 0 }, { maxY, maxPages, maxY, maxfilterResolution }, { 1, 1, 1, maxfilterResolution } };
Mode singleMode = { "SINGLE", { 1, 1, 1, 0 }, { maxY, maxX, maxY, maxfilterResolution }, { 1, 1, 1, maxfilterResolution } };
Mode volume_bpm = { "VOLUME_BPM", { 1, 0, 40, 1 }, { maxVolume, 0, maxBPM, maxVolume }, { 1, 0, 100, 9 } };
Mode noteShift = { "NOTE_SHIFT", { 7, 0, 7, 0 }, { 9, 0, 9, 0 }, { 8, 0, 8, 0 } };
Mode velocity = { "VELOCITY", { 1, 1, 1, 1 }, { 1, 1, maxY, maxY }, { 1, 1, 10, 10 } };
Mode set_Wav = { "SET_WAV", { 0, 1, 1, 0 }, { 999, maxFolders, 999, 999 }, { 0, 0, 1, 999 } };
Mode set_SamplePack = { "SET_SAMPLEPACK", { 1, 1, 1, 1 }, { 1, 1, 99, 99 }, { 1, 1, 1, 1 } };
Mode menu = { "MENU", { 1, 1, 1, 1 }, { 1, 1, 12, 12 }, { 1, 1, 1, 1 } };

// Declare currentMode as a global variable
Mode *currentMode = &draw;

// Declare the device struct
struct Device {
  unsigned int singleMode;  // single Sample Mod
  unsigned int currentChannel;
  unsigned int vol;           // volume
  unsigned int bpm;           // bpm
  unsigned int velocity;      // velocity
  unsigned int page;          // current page
  unsigned int edit;          // edit mode or plaing mode?
  unsigned int file;          // current selected save/load id
  unsigned int pack;          // current selected samplepack id
  unsigned int wav[maxY][2];  // current selected sample id
  unsigned int folder;        // current selected folder id
  bool activeCopy;            // is copy/paste active?
  unsigned int x;             // cursor X
  unsigned int y;             // cursor Y
  unsigned int seek;          // skipped into sample
  unsigned int seekEnd;
  unsigned int smplen;  // overall selected samplelength
  unsigned int shiftX;  // note Shift
  unsigned int shiftY;  // note Shift
  unsigned int filter_knob[maxFilters];
  unsigned int mute[maxY];
};



EXTMEM Device SMP = { false, 1, 10, 100, 10, 1, 1, 1, 1, { 1, 1, 1, 1, 1, 1, 1, 1, 1, 1, 1, 1, 1, 1, 1, 1 }, 0, false, 1, 16, 0, 0, 0, 0, 0, { maxfilterResolution, maxfilterResolution, maxfilterResolution, maxfilterResolution, maxfilterResolution, maxfilterResolution, maxfilterResolution, maxfilterResolution, maxfilterResolution, maxfilterResolution, maxfilterResolution, maxfilterResolution, maxfilterResolution, maxfilterResolution, maxfilterResolution }, {} };

Encoder encoders[4] = {
  Encoder(5, 22),   // 0, LEFT KNOB  (UP / DOWN, REMOVE TRIGGER, doubleTab: Enter/Exit Single-Sample-Mode)
  Encoder(4, 2),    // 1, RIGHT KNOB (LEFT / RIGHT, ADD TRIGGER)
  Encoder(9, 14),   // 2, MIDDLE LEFT KNOB (SELECT PAGE, double-tab+hold: set Accents), Long hold(+l/r knob): Select BPM OR VOLUME
                    // REMOVE IF YOU ONLY HAVE 3
  Encoder(32, 33),  // 3 Middle Right Knob
};

// DO YOU HAVE 4 ENCODERS? (s.above), set pins to 99,99 or similar
bool isEncoder4Defined = true;
// Filtering and Sample-End-Seeking is then disabled, volume is on left Knob



  Switch multiresponseButton1 = Switch(15);  // Left-Knob: (doubleTab: Enter/Exit Single-Sample-Mode)
  Switch multiresponseButton3 = Switch(16);  // Middle-Left: VOLUME / BPM
  Switch multiresponseButton4 = Switch(41);  // Middle-Right:
  Switch multiresponseButton2 = Switch(3);   // right-Knob:  (double-tab+hold: set Accents), Long hold(+l/r knob): Select BPM OR VOLUME




EXTMEM arraysampler _samplers[13];
AudioPlayArrayResmp *voices[] = { &sound0, &sound1, &sound2, &sound3, &sound4, &sound5, &sound6, &sound7, &sound8, &sound9, &sound10, &sound11, &sound12 };
AudioEffectEnvelope *envelopes[] = { &envelope0, &envelope1, &envelope2, &envelope3, &envelope4, &envelope5, &envelope6, &envelope7, &envelope8, &envelope9, &envelope10, &envelope11, &envelope12, &envelope13, &envelope14 };
AudioFilterStateVariable *filters[] = { &filter0, &filter1, &filter2, &filter3, &filter4, &filter5, &filter6, &filter7, &filter8, &filter9, &filter10, &filter11, &filter12, &filter13, &filter14 };

void serialprint(...) {
}

void serialprintln(...) {
}



void resetAllFilters() {
  for (unsigned int i = 0; i < maxFilters; i++) {
    //filters[i]->frequency(0);
    //filters[i]->resonance(0);
  }
}





void allOff() {
  for (AudioEffectEnvelope *envelope : envelopes) {
    envelope->noteOff();
  }
}

void FastLEDclear() {
  FastLED.clear();
}

void FastLEDshow() {
  if (millis() - lastUpdate > RefreshTime) {
    lastUpdate = millis();
    FastLED.show();
  }
}

void drawNoSD() {
  bool noSDfound = false;

  while (!SD.begin(SD_SLOT)) {
    FastLEDclear();
    for (unsigned int gx = 0; gx < 48; gx++) {
      light(noSD[gx][0], maxY - noSD[gx][1], CRGB(50, 0, 0));
    }
    FastLEDshow();
    delay(1000);
    noSDfound = true;
  }

  if (noSDfound && SD.begin(SD_SLOT)) {
    FastLEDclear();
    setLastFile();
    noSDfound = false;
  }
}

void copyPosValues(Mode *source, Mode *destination) {
  for (unsigned int i = 0; i < 3; i++) {
    destination->pos[i] = source->pos[i];
  }
}

void setVelocity() {
  if (currentMode->pos[2] != SMP.velocity) {

    if (!SMP.singleMode) {
      note[SMP.x][SMP.y][1] = round(mapf(currentMode->pos[2], 1, maxY, 1, 127));
    } else {
      serialprintln("Overal Velocity: " + String(currentMode->pos[2]));
      for (unsigned int nx = 1; nx < maxlen; nx++) {
        for (unsigned int ny = 1; ny < maxY + 1; ny++) {
          if (note[nx][ny][0] == SMP.currentChannel)
            note[nx][ny][1] = round(mapf(currentMode->pos[2], 1, maxY, 1, 127));
        }
      }
    }
  }
  drawVelocity(CRGB(0, 40, 0));
}
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
void loop() {

  // get USB MIdi clock
  usbMIDI.read();
  /*
    Serial.println("----------------");
    Serial.println(AudioMemoryUsageMax());
    Serial.println(AudioProcessorUsageMax());
    Serial.println("----------------");
    */

  // get EncoderButtonState
  multiresponseButton1.poll();
  multiresponseButton2.poll();
  multiresponseButton3.poll();
  multiresponseButton4.poll();
  // getEncoders
  checkPositions();

  // Set stateMashine
  if (currentMode->name == "DRAW") {
    canvas(false);
  } else if (currentMode->name == "VOLUME_BPM") {
    setVolume();
  } else if (currentMode->name == "VELOCITY") {
    setVelocity();
  } else if (currentMode->name == "SINGLE") {
    canvas(true);
  } else if (currentMode->name == "MENU") {
    showMenu();
  } else if (currentMode->name == "SET_SAMPLEPACK") {
    showSamplePack();
  } else if (currentMode->name == "SET_WAV") {
    showWave();


  } else if (currentMode->name == "NOTE_SHIFT") {
    shiftNotes();
    drawBase();
    drawSamples();
    if (isPlaying) {
      drawTimer(pagebeat);
    }
  }

  // reset buttons
  if (resetTimerActive && millis() - lastButtonPressTime > 80) {
    checkMode();
    memset(buttons, 0, sizeof(buttons));
    memset(oldButtons, 0, sizeof(oldButtons));
    resetTimerActive = false;  // Stop the timer
  }

  if (currentMode == &draw || currentMode == &singleMode) {
    drawBase();
    drawSamples();
    if (currentMode != &velocity)
      drawCursor();
    if (isPlaying) {
      drawTimer(pagebeat);
      FastLEDshow();
    }
  }

  // end synthsound after X ms
  if (noteOnTriggered && millis() - startTime >= 200) {
    envelope14.noteOff();
    envelope13.noteOff();
    noteOnTriggered = false;
  }

  FastLEDshow();  // draw!
  yield();
  delay(5);  // otherwise, the audio lib crashes after 1-60sec //(1 is good if 720MHZ overclock!!!!)
}

/******************************************************************************************************/

void canvas(bool singleview) {

  // CURSOR
  String posString = "Y:" + String(currentMode->pos[0]) + " X:" + String(currentMode->pos[2]) + " Page:" + String(currentMode->pos[1]);

  if (posString != oldPos) {
    oldPos = posString;
    SMP.x = currentMode->pos[2];
    SMP.y = currentMode->pos[0];

    if (paintMode) {
      note[(SMP.edit - 1) * maxX + SMP.x][SMP.y][0] = SMP.y - 1;
    }
    if (paintMode && currentMode == &singleMode) {
      note[(SMP.edit - 1) * maxX + SMP.x][SMP.y][0] = SMP.currentChannel;
    }

    if (unpaintMode) {
      if (SMP.singleMode) {
        if (note[(SMP.edit - 1) * maxX + SMP.x][SMP.y][0] == SMP.currentChannel)
          note[(SMP.edit - 1) * maxX + SMP.x][SMP.y][0] = 0;
      } else {
        note[(SMP.edit - 1) * maxX + SMP.x][SMP.y][0] = 0;
      }
    }

    unsigned int editpage = currentMode->pos[1];
    if (editpage != SMP.edit && editpage <= lastPage) {
      SMP.edit = editpage;
      serialprintln("p:" + String(SMP.edit));
    }
  }
}

void toggleCopyPaste() {
  if (!SMP.activeCopy) {
    // copy the pattern into the memory
    serialprint("copy now");
    unsigned int src = 0;
    for (unsigned int c = ((SMP.edit - 1) * maxX) + 1; c < ((SMP.edit - 1) * maxX) + (maxX + 1); c++) {  // maxy?
      src++;
      for (unsigned int y = 1; y < maxY + 1; y++) {
        serialprint(c);
        serialprint("-");
        serialprintln(y);

        for (unsigned int b = 0; b < 2; b++) {
          tmp[src][y][b] = note[c][y][b];
        }
      }
    }
  } else {
    // paste the memory into the song
    serialprint("paste here!");
    unsigned int src = 0;
    for (unsigned int c = ((SMP.edit - 1) * maxX) + 1; c < ((SMP.edit - 1) * maxX) + (maxX + 1); c++) {
      src++;
      for (unsigned int y = 1; y < maxY + 1; y++) {
        for (unsigned int b = 0; b < 2; b++) {
          note[c][y][b] = tmp[src][y][b];
        }
      }
    }
  }
  updateLastPage();
  SMP.activeCopy = !SMP.activeCopy;  // Toggle the boolean value
}

void clearNoteChannel(unsigned int c, unsigned int yStart, unsigned int yEnd, unsigned int channel, bool singleMode) {
  for (unsigned int y = yStart; y < yEnd; y++) {
    if (singleMode) {
      if (note[c][y][0] == channel)
        note[c][y][0] = 0;
      if (note[c][y][0] == channel)
        note[c][y][1] = defaultVelocity;
    } else {
      note[c][y][0] = 0;
      note[c][y][1] = defaultVelocity;
    }
  }
}

void clearPage() {
  unsigned int start = (SMP.edit - 1) * maxX + 1;
  unsigned int end = start + maxX;
  unsigned int channel = SMP.currentChannel;
  bool singleMode = SMP.singleMode;

  for (unsigned int c = start; c < end; c++) {
    clearNoteChannel(c, 1, maxY + 1, channel, singleMode);
  }
  updateLastPage();
}

void drawBPMScreen() {
  FastLEDclear();
  drawVolume(SMP.vol);
  CRGB volColor = CRGB(SMP.vol * SMP.vol, 20 - SMP.vol, 0);
  showIcons("helper_vol", volColor);
  showIcons("helper_bpm", CRGB(10, 10, 10));
  showNumber(SMP.bpm, false, -1);
}

void updateVolume() {

  if (!isEncoder4Defined) {
    SMP.vol = currentMode->pos[0];
  } else {
    SMP.vol = currentMode->pos[3];
  }
  float vol = float(SMP.vol / 10.0);
  serialprintln("Vol: " + String(vol));
  if (vol <= 1.0)
    sgtl5000_1.volume(vol);
  // setvol = true;
}

void updateBPM() {
  // setvol = false;
  serialprintln("BPM: " + String(currentMode->pos[2]));
  SMP.bpm = currentMode->pos[2];
  playNoteInterval = ((60 * 1000 / SMP.bpm) / 4) * 1000;
  playTimer.update(playNoteInterval);
  drawBPMScreen();
}

void setVolume() {
  drawBPMScreen();
  if (!isEncoder4Defined) {
    if (currentMode->pos[0] != SMP.vol) {
      updateVolume();
    }
  } else {
    if (currentMode->pos[3] != SMP.vol) {
      updateVolume();
    }
  }

  if (currentMode->pos[2] != SMP.bpm) {
    updateBPM();
  }
}

CRGB getCol(unsigned int g) {
  return col[g] * 10;
}

void drawVolume(unsigned int vol) {
  unsigned int maxXVolume = int(vol * 1.3) + 2;
  for (unsigned int y = 5; y <= 6; y++) {
    for (unsigned int x = 0; x <= maxXVolume; x++) {
      light(x + 1, y, CRGB(vol * vol, 20 - vol, 0));
    }
  }
}

void showMenu() {
  unsigned int knopf = 2;
  drawNoSD();
  FastLEDclear();

  showIcons("icon_loadsave", CRGB(10, 5, 0));
  showIcons("helper_select", CRGB(0, 0, 5));

  char OUTPUTf[50];
  sprintf(OUTPUTf, "%d.txt", SMP.file);
  if (SD.exists(OUTPUTf)) {
    showIcons("helper_save", CRGB(1, 0, 0));
    showIcons("helper_load", CRGB(0, 20, 0));
    showNumber(SMP.file, CRGB(0, 0, 20), 0);
  } else {
    showIcons("helper_save", CRGB(20, 0, 0));
    showIcons("helper_load", CRGB(0, 1, 0));
    showNumber(SMP.file, CRGB(20, 20, 40), 0);
  }
  FastLED.show();

  if (currentMode->pos[knopf] != SMP.file) {
    serialprint("File: " + String(currentMode->pos[knopf]));
    serialprintln();
    SMP.file = currentMode->pos[knopf];
  }
}

void showSamplePack() {
  drawNoSD();
  FastLEDclear();

  showIcons("icon_samplepack", CRGB(10, 10, 0));
  showIcons("helper_select", CRGB(0, 0, 5));
  showNumber(SMP.pack, CRGB(20, 0, 0), 0);

  char OUTPUTf[50];
  sprintf(OUTPUTf, "%d/%d.wav", SMP.pack, 1);
  if (SD.exists(OUTPUTf)) {
    showIcons("helper_load", CRGB(0, 20, 0));
    showIcons("helper_save", CRGB(3, 0, 0));
    showNumber(SMP.pack, CRGB(0, 20, 0), 0);
  } else {
    showIcons("helper_load", CRGB(0, 3, 0));
    showIcons("helper_save", CRGB(20, 0, 0));
    showNumber(SMP.pack, CRGB(20, 0, 0), 0);
  }
  FastLED.show();
  if (currentMode->pos[2] != SMP.pack) {
    serialprintln("File: " + String(currentMode->pos[2]));
    SMP.pack = currentMode->pos[2];
  }
}

void loadSamplePack(unsigned int pack) {
  serialprintln("Loading SamplePack #" + String(pack));
  drawNoSD();
  FastLEDclear();
  SMP.smplen = 0;
  SMP.seekEnd = 0;
  EEPROM.put(0, pack);

  for (unsigned int z = 1; z < maxFiles; z++) {
    FastLEDclear();
    showIcons("icon_sample", CRGB(20, 20, 20));
    drawLoadingBar(1, maxFiles, z, col[z], CRGB(15, 55, 15));
    loadSample(pack, z);
  }
  char OUTPUTf[50];
  sprintf(OUTPUTf, "%d/%d.wav", pack, 1);


  switchMode(&draw);
}
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

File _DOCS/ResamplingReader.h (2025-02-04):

#ifndef TEENSYAUDIOLIBRARY_RESAMPLINGREADER_H
#define TEENSYAUDIOLIBRARY_RESAMPLINGREADER_H

#include <Arduino.h>
#include <cstdint>
#include "loop_type.h"
#include "interpolation.h"
#include "waveheaderparser.h"

namespace newdigate {

template<class TArray, class TFile>
class ResamplingReader {
public:
    ResamplingReader() {
    }
    virtual ~ResamplingReader() {       
    }

    virtual TFile open(char *filename) = 0;
    virtual TArray* createSourceBuffer() = 0;
    virtual int16_t getSourceBufferValue(long index) = 0;
    virtual void close(void) = 0;

    void begin(void) 
    {
        if (_interpolationType != ResampleInterpolationType::resampleinterpolation_none) {
            initializeInterpolationPoints();
        }
        _playing = false;
        _crossfade = 0.0;
        if (_play_start == play_start::play_start_sample)
            _bufferPosition1 = _header_offset;
        else
            _bufferPosition1 = _loop_start;
        _file_size = 0;
    }

    bool playRaw(TArray *array, uint32_t length, uint16_t numChannels)
    {
        _sourceBuffer = array;
        stop();

        _header_offset = 0;
        _file_size = length * 2;
        _loop_start = 0;
        _loop_finish = length;
        setNumChannels(numChannels);

        reset();
        _playing = true;
        return true;
    }

    bool playRaw(TArray *array, uint16_t numChannels) {
        return playRaw(array, false, numChannels); 
    }

    bool playWav(TArray *array, uint32_t length) {
        return playRaw(array, true); 
    }

    bool play(const char *filename, bool isWave, uint16_t numChannelsIfRaw = 0)
    {
        close();

        if (!isWave) // if raw file, then hardcode the numChannels as per the parameter
            setNumChannels(numChannelsIfRaw);

        _filename = new char[strlen(filename)+1] {0};
        memcpy(_filename, filename, strlen(filename) + 1);

        TFile file = open(_filename);
        if (!file) {
            Serial.printf("Not able to open file: %s\n", _filename);
            if (_filename) delete [] _filename;
            _filename = nullptr;
            return false;
        }

        _file_size = file.size();
        if (isWave) {
            wav_header wav_header;
            wav_data_header data_header;

            WaveHeaderParser wavHeaderParser;
            char buffer[36];
            size_t bytesRead = file.read(buffer, 36);
            
            wavHeaderParser.readWaveHeaderFromBuffer((const char *) buffer, wav_header);
            if (wav_header.bit_depth != 16) {
                Serial.printf("Needs 16 bit audio! Aborting.... (got %d)", wav_header.bit_depth);
                return false;
            }
            setNumChannels(wav_header.num_channels);
            
            bytesRead = file.read(buffer, 8);
            unsigned infoTagsSize;
            if (!wavHeaderParser.readInfoTags((unsigned char *)buffer, 0, infoTagsSize))
            {
                Serial.println("Not able to read header! Aborting...");
                return false;
            }

            file.seek(36 + infoTagsSize);
            bytesRead = file.read(buffer, 8);

            if (!wavHeaderParser.readDataHeader((unsigned char *)buffer, 0, data_header)) {
                Serial.println("Not able to read header! Aborting...");
                return false;
            }

            _header_offset = (44 + infoTagsSize) / 2;
            _loop_finish = ((data_header.data_bytes) / 2) + _header_offset; 
        } else 
            _loop_finish = _file_size / 2;
        
        file.close();

        if (_file_size <= _header_offset * sizeof(int16_t)) {
            _playing = false;
            if (_filename) delete [] _filename;
            _filename =  nullptr;
            Serial.printf("Wave file contains no samples: %s\n", filename);
            return false;
        }

        _sourceBuffer = createSourceBuffer();
        _loop_start = _header_offset;

        reset();
        _playing = true;
        return true;
    }

    bool playRaw(const char *filename, uint16_t numChannelsIfRaw){
        return play(filename, false, numChannelsIfRaw);
    }
    
    bool playWav(const char *filename){
        return play(filename, true);
    }

    bool play()
    {
        stop();
        reset();
        _playing = true;
        return true;
    }

    void stop(void)
    {
        if (_playing) {   
            _playing = false;
        }
    }           

    bool isPlaying(void) { return _playing; }

    unsigned int read(void **buf, uint16_t nsamples) {
        if (!_playing) return 0;

        int16_t *index[_numChannels];
        unsigned int count = 0;
        for (int channel=0; channel < _numChannels; channel++) {
            index[channel] = (int16_t*)buf[channel];
        }

        while (count < nsamples) {
            for (int channel=0; channel < _numChannels; channel++) {
                if (readNextValue(index[channel], channel)) {
                    if (channel == _numChannels - 1)
                        count++;
                    index[channel]++;
                }
                else {
                    // we have reached the end of the file

                    switch (_loopType) {
                        case looptype_repeat:
                        {
                            _crossfade = 0.0;
                            if (_playbackRate >= 0.0) 
                                _bufferPosition1 = _loop_start;
                            else
                                _bufferPosition1 = _loop_finish - _numChannels;

                            break;
                        }

                        case looptype_pingpong:
                        {
                            if (_playbackRate >= 0.0) {
                                _bufferPosition1 = _loop_finish - _numChannels;
                            }
                            else {
                                if (_play_start == play_start::play_start_sample)
                                    _bufferPosition1 = _header_offset;
                                else
                                    _bufferPosition1 = _loop_start;
                            }
                            _playbackRate = -_playbackRate;
                            break;
                        }            

                        case looptype_none:            
                        default:
                        {
                            //Serial.printf("end of loop...\n");
                            /* no looping - return the number of (resampled) bytes returned... */
                            close();
                            return count;
                        }
                    }   
                }
            }
        }
        return count;
    }
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

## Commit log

2024-01-25 add usbMidi input and bugfix for scrolling left on pages
    [soundpauli_ni404.ino]
2024-01-28 added stl files of housing
    [Boden-hinten.stl, Boden-vorne.stl, Deckel.stl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]
2024-08-28 fixed noteShifting and velocity
    [soundpauli_ni404.ino]
2024-08-30 fixed autoload and sampleload
    [soundpauli_ni404.ino]
2024-11-10 refactor2: filebrowser, memory, fx, load, save, play
    [BOM.csv, Boden-hinten.stl, Boden-vorne.stl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]
2025-01-08 removed PCB because failures
    [BOM.csv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]
2025-02-04 added PCB and final code
    [BOM.csv, bom.csv, designators.csv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]
2025-02-04 updated files, new pcb
2025-02-04 added housing 3d and dxf
    [ni404 completed.stl, ni404_back.stl, ni404_base.stl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]
2025-02-07 cleaned up files3
    [BOM.csv, bom.csv, designators.csv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]
2025-02-07 cleaned up files4
    [BOM.csv, bom.csv, designators.csv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]
